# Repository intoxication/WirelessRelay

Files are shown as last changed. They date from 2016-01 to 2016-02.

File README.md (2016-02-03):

# Wireless Relay
Esp8266, Maple Mini powered wireless relay with up to 14 outputs
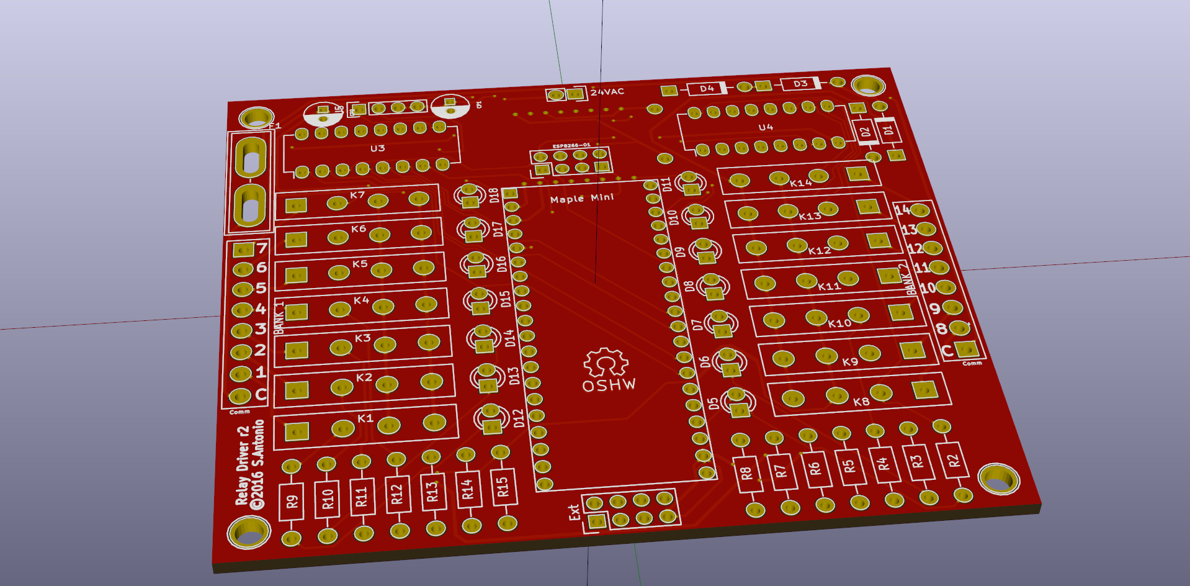
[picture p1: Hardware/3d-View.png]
3D Board Render r2


# Firmware 
Designed to run on maple mini (or clone) the device listens to local broadcast packets on port 15000

# Software
Runs under mono/C# allows users to control and query wireless device

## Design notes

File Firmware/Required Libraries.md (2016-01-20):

# Required Libraries

Compiles for Maple Mini against Arduino 1.6.5

https://github.com/rogerclarkmelbourne/Arduino_STM32
https://github.com/itead/ITEADLIB_Arduino_WeeESP8266

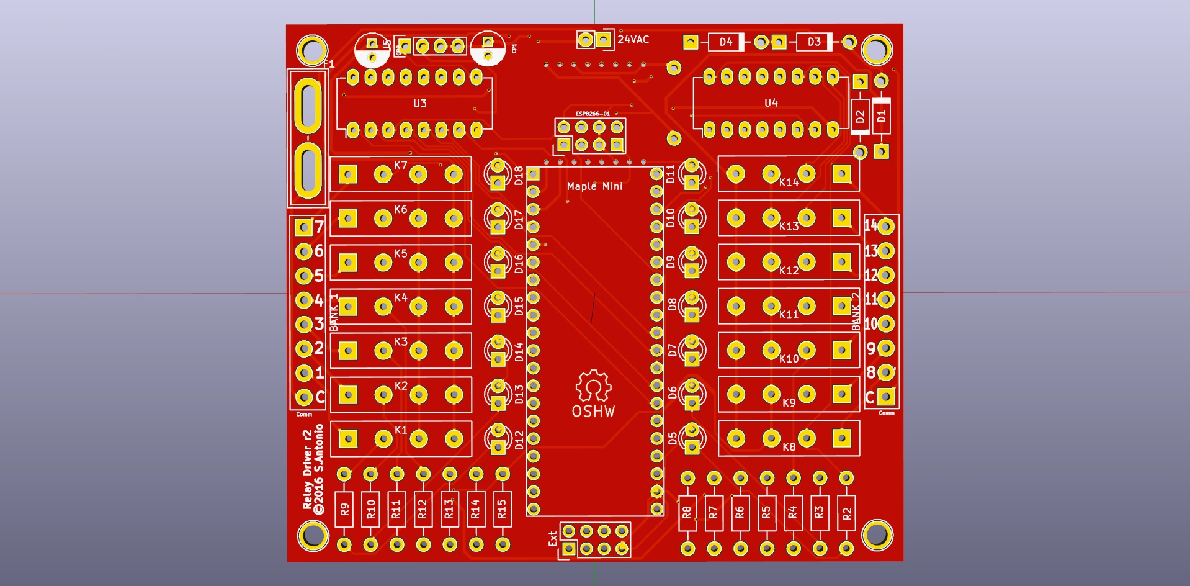
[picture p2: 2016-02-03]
Hardware/Front-View.png

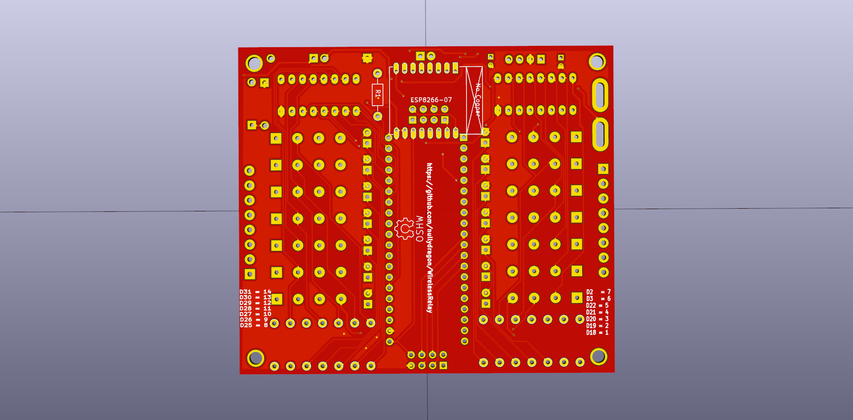
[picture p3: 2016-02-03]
Hardware/Back-View.png

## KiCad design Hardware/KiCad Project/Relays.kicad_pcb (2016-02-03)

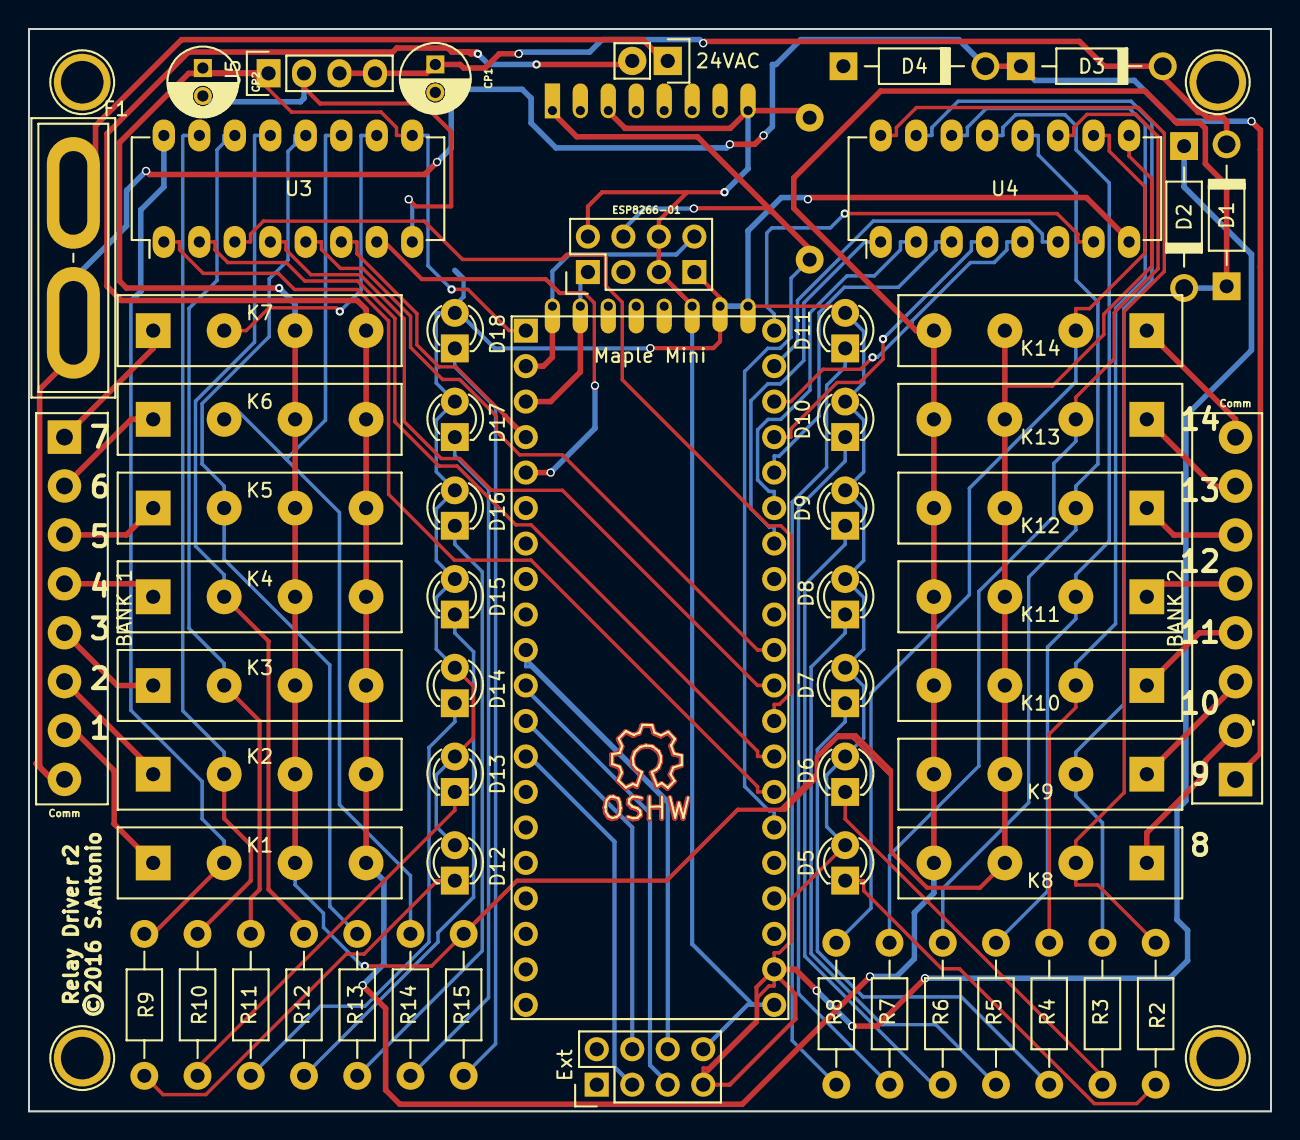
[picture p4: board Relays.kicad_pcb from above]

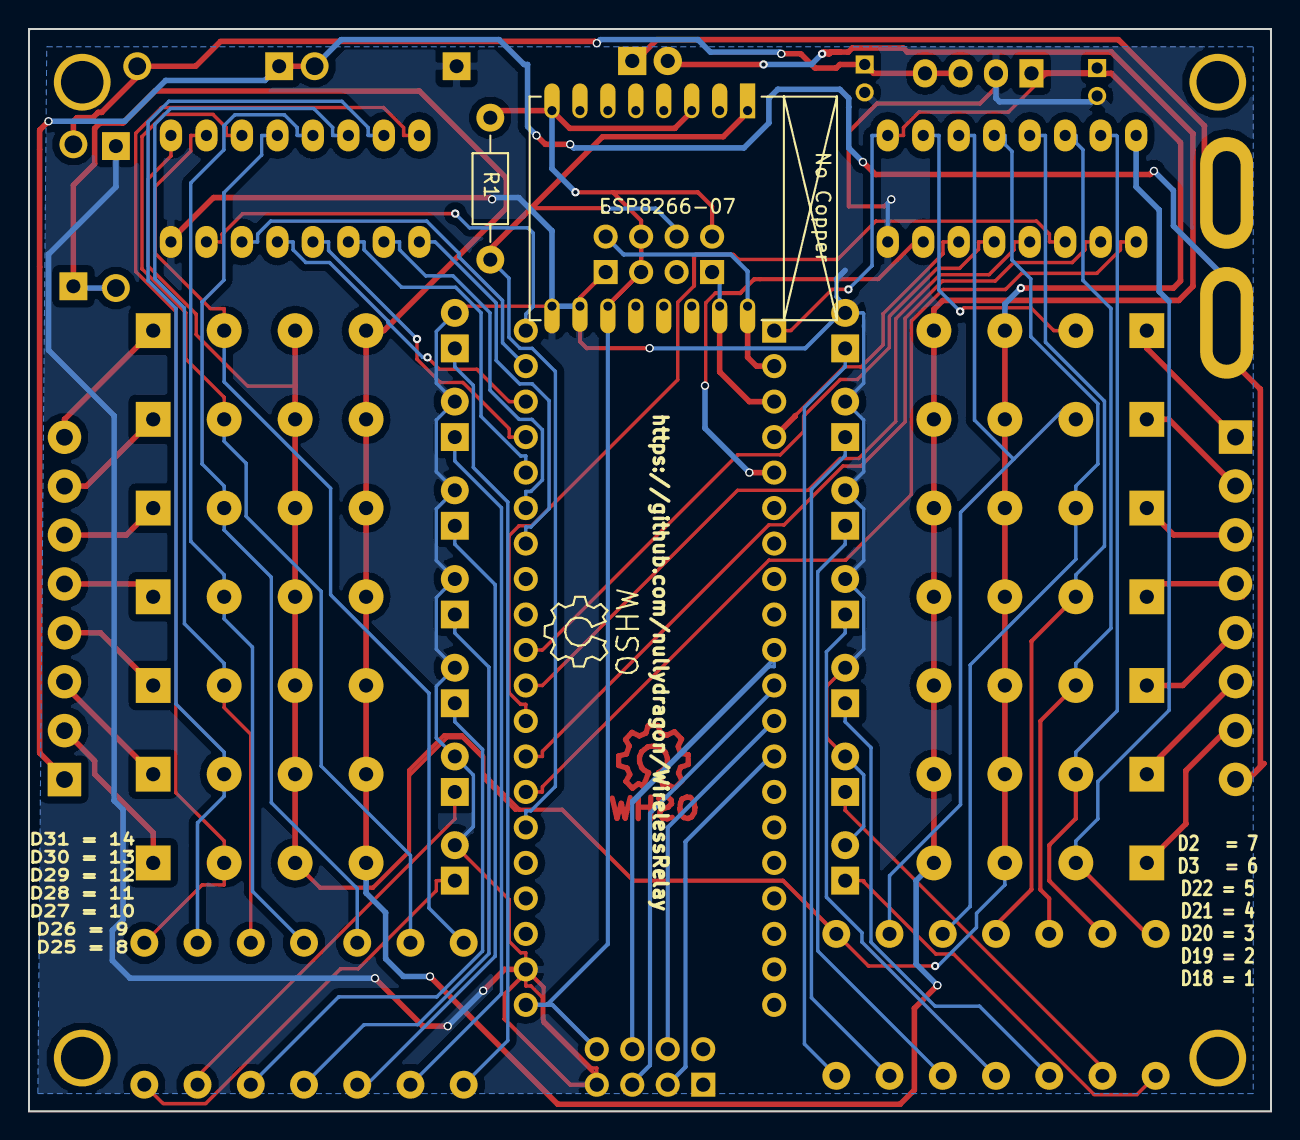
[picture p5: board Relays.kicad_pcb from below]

Board: 2 copper layers, 88.9 x 77.5 mm, 67 parts (3 on the bottom side), 69 nets.

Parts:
BANK 1, BANK 2: Comm; TerminalBlock_Pheonix_PT-3.5mm_8pol
CP1: CP1; C_Radial_D5_L11_P2
CP2: CP2; C_Radial_D5_L11_P2
D1, D2, D3, D4: DIODE; Diode_DO-41_SOD81_Horizontal_RM10
D5, D6, D7, D8, D9, D10, D11, D12, D13, D14, D15, D16, D17, D18: LED; LED-3MM
ESP8266-01: ESP8266-02; Pin_Header_Straight_2x04
ESP8266-07: ESP-07v2
F1: BladeFuse-CarType
K1, K2, K3, K4, K5, K6, K7, K8, K9, K10, K11, K12, K13, K14: SIP-1A05
LOGO1, LOGO2: Symbol_OSHW-Logo_SilkScreen
LOGO3: Symbol_OSHW-Logo_CopperTop
MNT1, MNT2, MNT3, MNT4: 1pin
Maple Mini: Maple Mini; Pin_Header_Straight_2x20
P1: 24VAC; Pin_Header_Straight_1x02
P2: Ext; Pin_Header_Straight_2x04
R1: 10k; Resistor_Horizontal_RM10mm
R2, R3, R4, R5, R6, R7, R8, R9, R10, R11, R12, R13, R14, R15: R; Resistor_Horizontal_RM10mm
U3, U4: ULN2003AN; DIP-16_W7.62mm_LongPads
U5: D24V3F5; Pin_Header_Straight_1x04

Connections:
+3.3V: ESP8266-01.2, ESP8266-01.5, ESP8266-01.6, ESP8266-07.3, ESP8266-07.8, ESP8266-07.11, Maple Mini.40, P2.8, R1.1
+5V: CP2.1, K1.3, K2.3, K3.3, K4.3, K5.3, K6.3, K7.3, K8.3, K9.3, K10.3, K11.3, K12.3, K13.3, K14.3, Maple Mini.1, R15.1, U3.9, U4.9, U5.1
+36V: CP1.1, D1.2, D3.2, U5.3, U5.4
/AC1: D1.1, D2.2, K1.4, K2.4, K3.4, K4.4, K5.4, K6.4, K7.4, K8.4, K9.4, K10.4, K11.4, K12.4, K13.4, K14.4, P1.2
/AC2: BANK 1.8, BANK 2.1, D3.1, D4.2, F1.1, F1.2, P1.1
/D8: Maple Mini.19, P2.6
/D9: Maple Mini.21, P2.5
/D10: Maple Mini.23, P2.4
/D11: Maple Mini.25, P2.3
/D17: ESP8266-01.4, ESP8266-07.1, Maple Mini.30, R1.2
/D18: Maple Mini.28, U3.1
/D19: Maple Mini.26, U3.2
/D20: Maple Mini.24, U3.3
/D21: Maple Mini.22, U3.4
/D22: Maple Mini.20, U3.5
/D23: Maple Mini.7, U3.6
/D24: Maple Mini.9, U3.7
/D25: Maple Mini.14, U4.1
/D26: Maple Mini.12, U4.2
/D27: Maple Mini.10, U4.3
/D28: Maple Mini.8, U4.4
/D29: Maple Mini.6, U4.5
/D30: Maple Mini.4, U4.6
/D31: Maple Mini.2, U4.7
/RL1: K8.2, R2.1, U4.16
/RL2: K9.2, R3.1, U4.15
/RL3: K10.2, R4.1, U4.14
/RL4: K11.2, R5.1, U4.13
/RL5: K12.2, R6.1, U4.12
/RL6: K13.2, R7.1, U4.11
/RL7: K14.2, R8.1, U4.10
/RL8: K1.2, R9.1, U3.16
/RL9: K2.2, R10.1, U3.15
/RL10: K3.2, R11.1, U3.14
/RL11: K4.2, R12.1, U3.13
/RL12: K5.2, R13.1, U3.12
/RL13: K6.2, R14.1, U3.11
/RX3: ESP8266-01.8, ESP8266-07.16, Maple Mini.3
/TX3: ESP8266-01.1, ESP8266-07.15, Maple Mini.5
GND: CP1.2, CP2.2, D2.1, D4.1, D5.2, D6.2, D7.2, D8.2, D9.2, D10.2, D11.2, D12.2, D13.2, D14.2, D15.2, D16.2, D17.2, D18.2, ESP8266-01.7, ESP8266-07.9, ESP8266-07.10, Maple Mini.38, P2.7, U3.8, U4.8, U5.2
unnamed: D5.1, R2.2
unnamed: D6.1, R3.2
unnamed: D7.1, R4.2
unnamed: D8.1, R5.2
unnamed: D9.1, R6.2
unnamed: D10.1, R7.2
unnamed: D11.1, R8.2
unnamed: D12.1, R9.2
unnamed: D13.1, R10.2
unnamed: D14.1, R11.2
unnamed: D15.1, R12.2
unnamed: D16.1, R13.2
unnamed: D17.1, R14.2
unnamed: D18.1, R15.2
unnamed: BANK 1.7, K1.1
unnamed: BANK 1.6, K2.1
unnamed: BANK 1.5, K3.1
unnamed: BANK 1.4, K4.1
unnamed: BANK 1.3, K5.1
unnamed: BANK 1.2, K6.1
unnamed: BANK 1.1, K7.1
unnamed: K7.2, U3.10
unnamed: BANK 2.2, K8.1
unnamed: BANK 2.3, K9.1
unnamed: BANK 2.4, K10.1
unnamed: BANK 2.5, K11.1
unnamed: BANK 2.6, K12.1
unnamed: BANK 2.7, K13.1
unnamed: BANK 2.8, K14.1

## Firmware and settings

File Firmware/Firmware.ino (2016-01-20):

#include <ESP8266.h>
#include <libmaple/iwdg.h>

#include "Commands.h"
#include "config.h"

//#define DEBUG
#define VERBOSE_SETUP

ESP8266 *wifi;
Commander *commander;

void setup() {
  
  // put your setup code here, to run once:
#ifdef VERBOSE_SETUP
  Serial.println("Turning off relays...");
#endif
  pinMode(D18, OUTPUT);
  pinMode(D19, OUTPUT);
  pinMode(D20, OUTPUT);
  pinMode(D21, OUTPUT);
  pinMode(D22, OUTPUT);
  pinMode(D23, OUTPUT);
  pinMode(D24, OUTPUT);
  pinMode(D25, OUTPUT);
  pinMode(D26, OUTPUT);
  pinMode(D27, OUTPUT);
  pinMode(D28, OUTPUT);
  pinMode(D29, OUTPUT);
  pinMode(D30, OUTPUT);
  pinMode(D31, OUTPUT);

  digitalWrite(D18, 0);
  digitalWrite(D19, 0);
  digitalWrite(D20, 0);
  digitalWrite(D21, 0);
  digitalWrite(D22, 0);
  digitalWrite(D23, 0);
  digitalWrite(D24, 0);
  digitalWrite(D25, 0);
  digitalWrite(D26, 0);
  digitalWrite(D27, 0);
  digitalWrite(D28, 0);
  digitalWrite(D29, 0);
  digitalWrite(D30, 0);
  digitalWrite(D31, 0);

#ifdef VERBOSE_SETUP
  Serial.println("Waiting for system to settle...");
#endif

  delay(5000);

  Serial.println("Starting Simple Relay Setup");

  Serial3.begin(9600);

#ifdef VERBOSE_SETUP
  Serial.println("Creating Wifi Device...");
#endif
  
  wifi = new ESP8266(Serial3, 9600);

  wifi->kick();
  wifi->setOprToStation();

  delay(2000);

#ifdef VERBOSE_SETUP
  Serial.println("Connecting to AP...");
#endif
  if(!wifi->joinAP(SSID,PASSWORD)) {
    Serial.println("Unable to connect to access point");
  }

  //doesnt work
  Serial.print("Local Ip: " );
  Serial.println(String(wifi->getLocalIP()));

  wifi->enableMUX();

#ifdef VERBOSE_SETUP
  Serial.println("Set to Mode to UDP");
#endif
  wifi->registerUDP( 1,HOST,PORT);


#ifdef VERBOSE_SETUP
  Serial.println("Setup as local server...");
#endif
  if(!wifi->startServer(PORT)) {
    Serial.println("Unable to start server");
  }
  else
  {
    Serial.println("Failed to start local server...");
  }

  Serial.print("ESP8266 Firmware version: " );
  Serial.println(wifi->getVersion());

#ifdef VERBOSE_SETUP
  Serial.println("Setup commander...");
#endif
  commander = new Commander(wifi);

  Serial.println("Simple Relay Driver r1 Now Ready...");

  //setup an 8 second watch dog timer
  iwdg_init(IWDG_PRE_256, 1250);

  //send hello
  Identify(1);
}

void loop() {    
  commander->update();

  //Test the wifi connection
  if(wifi->send(1, (const uint8_t*)DEVICE_ID, sizeof(DEVICE_ID) / sizeof(char)))
  {
	  //wifi is ok.	  
	  //feed the watch dog so we don't reset
	  iwdg_feed();
  }
  else {
	  reconnect();	  
  }
}

void reconnect()
{
#ifdef VERBOSE_SETUP
  Serial.println("Trying to reconnect - Send Failed");
#endif

  //try reconnect
  wifi = new ESP8266(Serial3, 9600);

  wifi->kick();
  wifi->setOprToStation();
  if(!wifi->joinAP(SSID,PASSWORD)) {
    Serial.println("Unable to connect to access point");
  }

  delay(200);
  
  //doesnt work
  Serial.print("Local Ip: " );
  Serial.println(String(wifi->getLocalIP()));

  wifi->enableMUX();
  
  wifi->registerUDP( 1,HOST,PORT);

  delay(200);

#ifdef VERBOSE_SETUP
  Serial.println("Setup as local server...");
#endif
  if(!wifi->startServer(PORT)) {
    Serial.println("Unable to start server");
  }
  else
  {
    Serial.println("Failed to start local server...");
  }

  delay(200);
}

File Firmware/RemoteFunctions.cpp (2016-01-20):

#include "RemoteFunctions.h"
#include <Arduino.h>

extern ESP8266 *wifi;

void SetPinOn(int p)
{  
  Serial.print("Set Pin ON ");
  Serial.println(p);
  
  digitalWrite(p + PIN_OFFSET, 1);

  //read pin state
  int ps = digitalRead(p + PIN_OFFSET);

  char tempBuff[18] = {'\0'};
  sprintf(tempBuff, "ACK/PIN_ON/%d/%d", p, ps);
  
  wifi->send(1,(const uint8_t*)tempBuff, sizeof(tempBuff) / sizeof(char));
}

void SetPinOff(int p)
{
  Serial.print("Set Pin OFF ");
  Serial.println(p);
  
  digitalWrite(p + PIN_OFFSET, 0);

    //read pin state
  int ps = digitalRead(p + PIN_OFFSET);

  char tempBuff[18] = {'\0'};
  sprintf(tempBuff, "ACK/PIN_OFF/%d/%d", p, ps);

  wifi->send(1,(const uint8_t*)tempBuff, sizeof(tempBuff) / sizeof(char));
}

void GetDeviceState(int)
{  
  Serial.println("Get Device State");
  
  int portA = GPIOA->regs->ODR;//BSRR
  int portB = GPIOB->regs->ODR;
  int portC = GPIOC->regs->ODR;
  
  String command(DEVICE_ID);
  command += "/STATE/";
  command += portA ;
  command += "," ;
  command += portB  ;
  command += "," ;
  command += portC;

  char tempBuff[64] = {'\0'};
  command.toCharArray(tempBuff, sizeof(tempBuff) / sizeof(char));
  
  wifi->send(1,(const uint8_t*)tempBuff, sizeof(tempBuff) / sizeof(char));

  Serial.print("send: ");
  Serial.println(command.c_str());

  delay(2);
}

void Identify(int i) 
{
  if(i == 1) {
    char hello[] = { 'Online\r\n\0' };
    wifi->send(1,(const uint8_t*)hello, sizeof(hello) / sizeof(char));
  }
  else
    wifi->send(1,(const uint8_t*)DEVICE_ID, sizeof(DEVICE_ID) / sizeof(char));
}

void USBOff(int)
{
  Serial.println("USB Powering down - to reconnect send the \"USB_ON/0\" command");
  Serial.end();
}
void USBOn(int)
{
  Serial.println("USB restored"); 
  Serial.begin();
}

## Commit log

2016-01-20 Add wireless relay hardware files for use with KiCAD
    [Large-B_Cu.gbl, Large-B_Cu.gbr, Large-B_Mask.gbs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]
2016-01-20 add maple mini firmware to run the wireless relay board
2016-01-31 tweaked firmware broadcast to send status of device
2016-02-03 added esp826601 bigger headers and fuse
    [Relays-B.Cu.gbl, Relays-B.Mask.gbs, Relays-B.SilkS.gbo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]
2016-02-03 tweaked silkscreen and footprints slightly
    [Relays-B.Cu.gbl, Relays-B.Mask.gbs, Relays-B.SilkS.gbo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]
2016-02-03 fixes silk screen
    [Relays-B.Cu.gbl, Relays-B.Mask.gbs, Relays-B.SilkS.gbo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]

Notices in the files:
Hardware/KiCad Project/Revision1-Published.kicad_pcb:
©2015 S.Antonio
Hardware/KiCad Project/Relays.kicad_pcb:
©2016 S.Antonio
